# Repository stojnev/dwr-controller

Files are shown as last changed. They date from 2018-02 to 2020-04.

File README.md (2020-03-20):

# dŵr controller

"dŵr controller" ("dŵr") is a relatively simple closed loop snippet to provide two basic functionalities to a turntable drive system - (1) RPM counter and (2) feedback for an external motor controller.

It also aims to do some psychoacoustic majic in between code loops.

## Features

- Calculates RPM from up to 12 (*) control points on a turntable platter via a single sensor;
- Handles an external controller through a rough PI loop (running speed, speed mode (33/45) and control method);
- Rough PI parameter auto-tune;
- Dynamically calculates a standardized wow value, averaged over the control cycle.;

(*) Technically, can be as many as needed, or as many as can physically fit on the turntable platter.

## Description

"dŵr" acts principally as a tachometer, utilizing a combination of magnets attached to the underside of a turntable drive platter, and a single fixed location hall effect sensor, connected to an Arduino (Nano for most of principal development). This information is continuously displayed on an OLED screen controlled via I2C.

Assembled data derives a difference quotient from desired speed which is then used to send commands to an external controller. (**)

(**) Development has revolved mostly around the SG4 sinewave generator, courtesy of Pyramid on DIYAudio.com.

Additional features include:

- Calculation of wow as a primary component of W&F;
- Recording of standard play time to gauge cartridge life;
- Dynamic parameter logging for latter analyses. 

## Dependencies

- [OneButton](https://github.com/mathertel/OneButton) 
- [U8G2](https://github.com/olikraus/u8g2)

## Hardware

- Arduino Nano (or similar)
- Hall Effect Sensor (or an optical sensor)
- Magnets (or strips of reflective tape for an optical sensor)
- OLED (using a SSD1306 based 0.91" via I2C)
- BC337 (or similar NPN transistor) (***)
- 1kOhm resistors

(***) Replaced CD4066B switch as it was unreliable in this application.

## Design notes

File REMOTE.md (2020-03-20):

# dŵr controller

"dŵr controller" ("dŵr") uses two pushbuttons to access / activate various features. In order to have a minimal number of buttons, yet retain full functionality, dŵr relies on a combination of (1) various button events (short press, long press) and (2) turntable running state (spinning, not spinning).

* [LSP] - Left button press;
* [LDP] - Left button hold press;
* [RSP] - Right button press;
* [RDP] - Right button hold press;

Left button refers to momentary switch typically connected to pin 4, right button refers to switch typically connected to pin 5.

## Platter Not Spinning

* [LSP] Start rotation.
* [RDP] Access play time for cartridge life.

## Timer Mode Active

* [LDP] Reset play time for cartridge life.
* [RDP] Exit timer mode.

## Platter Spinning

* [LSP] Stop rotation.
* [LDP] Show calculated W&F.
* [RSP] Change rotation speed (33/45).
* [RDP] Switch between automatic speed regulation and manual speed regulation (no feedback).

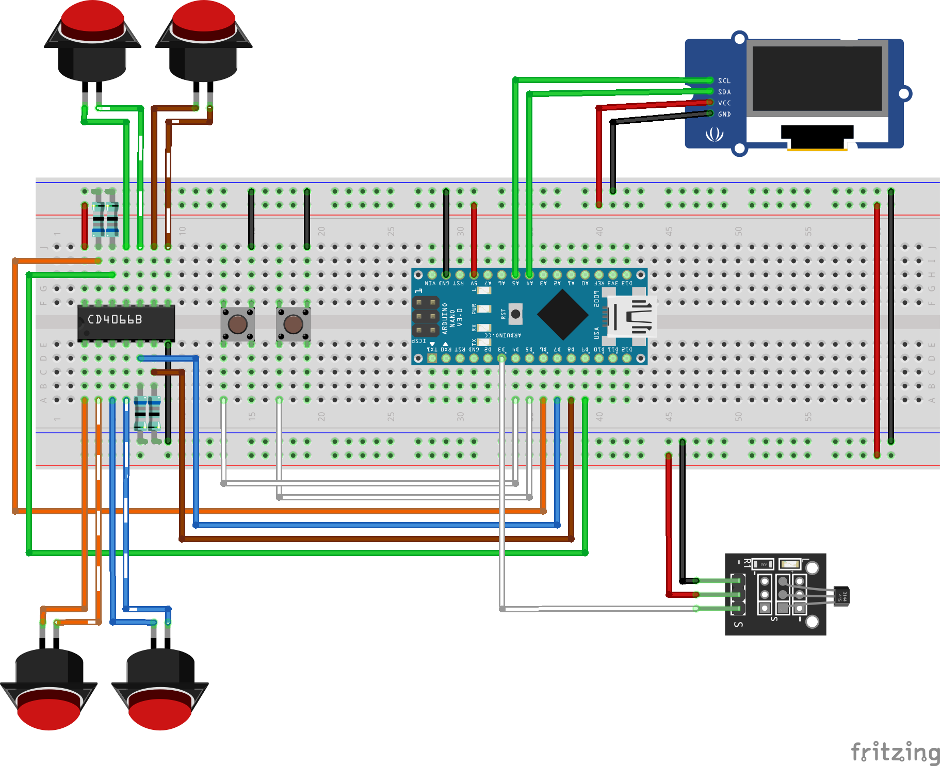
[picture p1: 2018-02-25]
breadboards/dwr-controller-v0.1.png

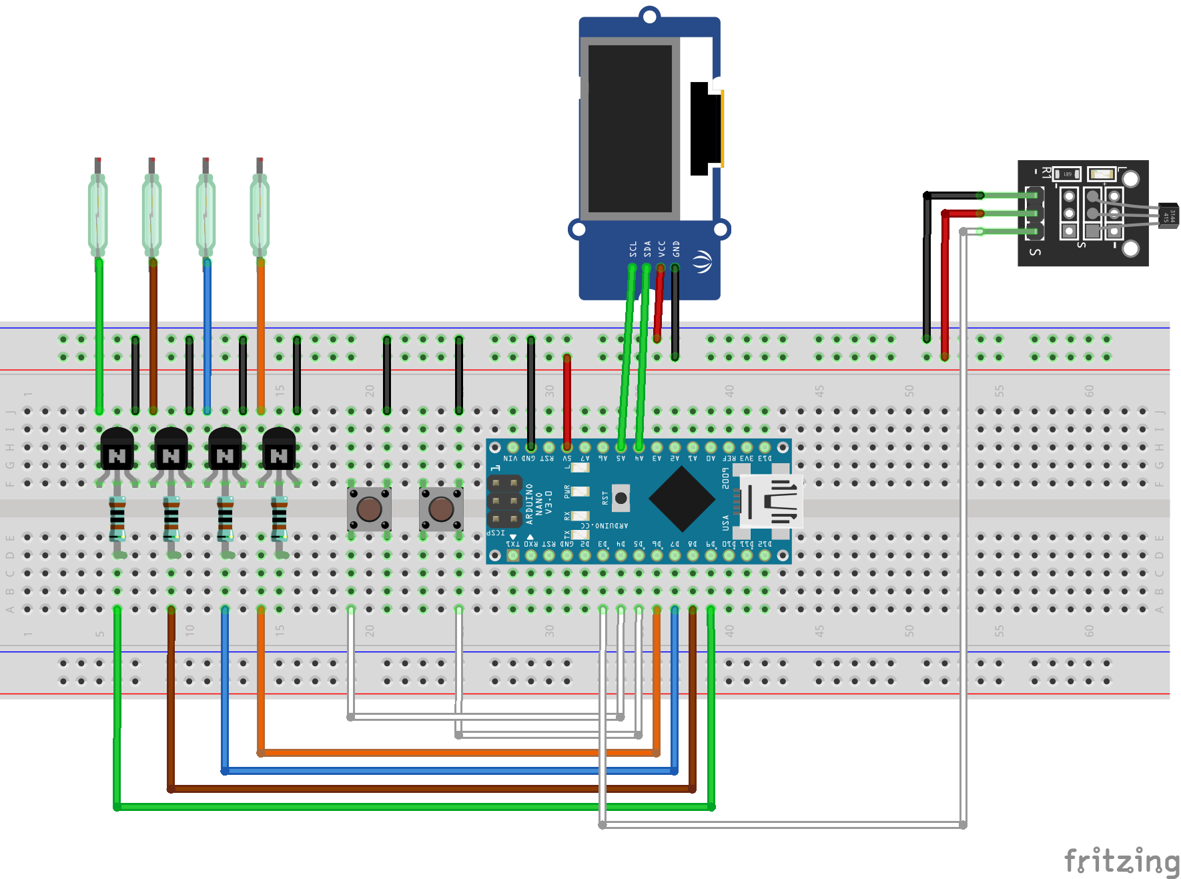
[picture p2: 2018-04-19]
breadboards/dwr-controller-v0.2.png

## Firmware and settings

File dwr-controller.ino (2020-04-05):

#include <OneButton.h>
#include <U8g2lib.h>
#include <EEPROM.h>

#define dwrlogo_width 60
#define dwrlogo_height 30
static const unsigned char dwrlogo_bits[] PROGMEM = {
  0x00, 0xf0, 0x03, 0x00, 0x02, 0x00, 0x00, 0x00, 0x00, 0xf0, 0x03, 0x00,
  0x07, 0x00, 0x00, 0x00, 0x00, 0xf0, 0x03, 0x80, 0x0f, 0x00, 0x00, 0x00,
  0x00, 0xf0, 0x03, 0xe0, 0x3f, 0x00, 0x00, 0x00, 0x00, 0xf0, 0x03, 0xf0,
  0x7f, 0x00, 0x00, 0x00, 0x00, 0xf0, 0x03, 0xf8, 0xfd, 0x00, 0x00, 0x00,
  0x00, 0xf0, 0x03, 0xf8, 0xf8, 0x00, 0x00, 0x00, 0x00, 0xf0, 0x03, 0x30,
  0x60, 0x00, 0x00, 0x00, 0x00, 0xf0, 0x03, 0x00, 0x00, 0x00, 0x00, 0x00,
  0x00, 0xf0, 0x03, 0x00, 0x00, 0x00, 0x00, 0x00, 0x00, 0xf0, 0x03, 0x00,
  0x00, 0x00, 0x00, 0x00, 0x00, 0xf0, 0x03, 0x00, 0x00, 0x00, 0x00, 0x00,
  0xc0, 0xf7, 0x03, 0x00, 0x02, 0x00, 0x80, 0x0f, 0xf0, 0xff, 0xe3, 0x07,
  0x07, 0x3f, 0xcf, 0x0f, 0xf8, 0xff, 0xe3, 0x87, 0x0f, 0x3f, 0xef, 0x0f,
  0xfc, 0xff, 0xc3, 0x87, 0x0f, 0x1f, 0xff, 0x0f, 0xfe, 0xff, 0xc3, 0xcf,
  0x9f, 0x1f, 0xff, 0x07, 0xfe, 0xff, 0xc3, 0xef, 0xbf, 0x1f, 0xff, 0x03,
  0x7f, 0xf0, 0x83, 0xef, 0xbf, 0x0f, 0x7f, 0x00, 0x3f, 0xe0, 0x83, 0xff,
  0xff, 0x0f, 0x3f, 0x00, 0x3f, 0xe0, 0x83, 0xff, 0xff, 0x0f, 0x3f, 0x00,
  0x3f, 0xe0, 0x03, 0xff, 0xff, 0x07, 0x3f, 0x00, 0x3f, 0xe0, 0x03, 0xff,
  0xfd, 0x07, 0x3f, 0x00, 0x7e, 0xf0, 0x03, 0xff, 0xf8, 0x07, 0x3f, 0x00,
  0xfe, 0xff, 0x03, 0x7e, 0xf0, 0x03, 0x3f, 0x00, 0xfc, 0xff, 0x03, 0x7e,
  0xf0, 0x03, 0x3f, 0x00, 0xfc, 0xff, 0x03, 0x3c, 0xe0, 0x01, 0x3f, 0x00,
  0xf8, 0xbf, 0x03, 0x1c, 0xc0, 0x01, 0x3f, 0x00, 0xe0, 0x8f, 0x03, 0x1c,
  0xc0, 0x01, 0x3f, 0x00, 0x80, 0x07, 0x00, 0x08, 0x80, 0x00, 0x3f, 0x00
};

U8G2_SSD1306_128X32_UNIVISION_F_HW_I2C u8g2(U8G2_R0, U8X8_PIN_NONE);

#define pinSensor 3
#define pinButtonSTB 4
#define pinButtonSWT 5
#define pinSwitchSTB 6
#define pinSwitchSWT 7
#define pinSwitchUP 8
#define pinSwitchDWN 9

int pseudoClickDelay = 25;
const int triggerNumber = 4; // Indicates the number of sensor triggers per rotation.
boolean debugSerial = true; // Determines if output written to serial (mostly if not exclusively for debugging purposes).
boolean tachometerOnly = false; // A setting of "true" disables pseudoClickButton() and switchRotationSpeed() for the code to work as tachometer only.
volatile unsigned long timeHallNew[8]; volatile unsigned long timeHallPrevious[8]; // Variables pairs to hold new and old times for sensor triggers - arrays are provisioned to account for a maximum of 8 sensor triggers.
boolean activeSpin = false; boolean justStarted = true; boolean modeAutomatic = true; // Variables to indicate whether (1) actively spinning, (2) just started spinning (legacy purpose) and (3) status of automatic correction.
long countSpin = 0; int countTempSpin = 0; // Variables to hold (1) number of full spins since start and (2) intermediary spin portions between full spins based on number of sensor triggers.
int spinSpeed = 0; // Variable to hold speed of spinning, where 0 = 33.33 and 1 = 45.00.
int countMessageDisplaySpins = 1; int waitingCycle = 0; long stoppingTime = 2500000; // Indicates (1) the number of rotations a display message is active before being replaced with RPM, (2) represents intermediary counter and (3) determines the amount of microseconds elapsed after which the platter is considered stopped.
int correctionSpin = 3; int correctionSpinShort = 2; long correctionSpinCount = 0; int correctionMovement = 5; // Indicates (1) number of rotations to wait for applying correction with small corrections, (2) number of rotations to wait for applying correction with large corrections, (3) temporary spin count and (4) maximum amount of steps to correct per cycle.
float correctionQ = 0.01; // Indicates the difference quotient from standard speed to activate automatic correction.
float derivedQ = 0.01; // Indicates the correction in RPM derived from a single 0.01Hz step (single "click").
float totalWF = 0;
boolean averageCalc = true, averageCompleted = false; const int averageTotal = 16; int averageCount = 0; float averageValues[averageTotal]; boolean averageFlip = false; // Indicates (1) whether to do averaging and (2) if first pass of averaging completed, (3) number of passes for each averaging.
float fixRPM = 0, fixSteps = 0; // Variables for programmatic calculation of derivedQ.
const float setQ = 0.01;
unsigned long timerCurrentMicros = 0, timerPreviousMicros = 0;
const int timerSlots = 4; int timerX[timerSlots]; const int timerMessageWait = 5000; long timerMessage = 0; boolean timerShown = false;

OneButton buttonSTB(pinButtonSTB, true);
OneButton buttonSWT(pinButtonSWT, true);

void setup()
{
  // Correct spin counting variables when using more than one trigger per spin cycle.
  countMessageDisplaySpins = countMessageDisplaySpins * triggerNumber;

  // Initialize buttons, switches and displays.
  initializeButtonsSwitchesSensors();
  u8g2.begin();
  drawLogo();

  if (debugSerial) {
    Serial.begin(9600);
  }
}

void loop()
{
  buttonSTB.tick();
  buttonSWT.tick();
  if (timerMessage > 0)
  {
    if (millis() > (timerMessage + timerMessageWait))
    {
      timerMessage = 0;
      timerShown = false;
      drawLogo();
    }
  }
  if (activeSpin)
  {
    unsigned long currentMicros = micros();
    checkTimer();
    if (justStarted)
    {
      writeToDisplay(3);
      justStarted = false;
    }
    if (timeHallNew[countTempSpin] > timeHallPrevious[countTempSpin]) {
      if (countSpin > 1) { showRPM(); }
    }
    else if (currentMicros - timeHallNew[countTempSpin] > stoppingTime) // Show waiting message after ~2.5 seconds of no new pulses, but only if pulses were detected.
    {
      stopSpin();
    }
    timeHallPrevious[countTempSpin] = timeHallNew[countTempSpin];
    delay(pseudoClickDelay);
  }
}

void stopSpin()
{
  // Default to 33.33 RPM to allow for smoother start-up.
  spinSpeed = 0;
  digitalWrite(pinSwitchSWT, LOW);

  // Reset active rotation variables.
  activeSpin = false;
  countSpin = 0;
  countTempSpin = 0;
  correctionSpinCount = 0;
  drawLogo();
  averageCount = 0;
  averageCompleted = false;
  fixSteps = 0;
  timerCurrentMicros = 0;
  timerPreviousMicros = 0;
  timerMessage = 0;

}

void initializeButtonsSwitchesSensors()
{
  if (!tachometerOnly)
  {
    for (int p = 6; p <= 9; p++)
    {
      pinMode(p, OUTPUT);
      digitalWrite(p, LOW);
    }
    buttonSTB.attachClick(startOperation);
    buttonSTB.attachLongPressStart(clearTimer);
    buttonSWT.attachClick(switchRotationSpeed);
    buttonSWT.attachLongPressStart(switchAutomaticMode);
  }
  pinMode(pinSensor, INPUT_PULLUP);
  attachInterrupt(digitalPinToInterrupt(pinSensor), triggerSensor, FALLING);
}

void startOperation()
{
  if (activeSpin)
  {
    stopSpin();
    activeSpin = false;
  }
  else
  {
    justStarted = true;
  }
  pseudoClickButton(pinSwitchSTB);
  timerMessage = 0;
}

void switchRotationSpeed()
{
  if (tachometerOnly) { return; }
  if (!activeSpin) { return; }
  spinSpeed++;
  if (spinSpeed > 1) {
    spinSpeed = 0;
    digitalWrite(pinSwitchSWT, LOW);
  }
  else {
    digitalWrite(pinSwitchSWT, HIGH);
  }
  correctionSpinCount = 0;
  averageCount = 0;
  averageCompleted = false;
  averageFlip = true;
  fixSteps = 0;
  writeToDisplay(2);
}

void switchAutomaticMode()
{
  if (tachometerOnly) {
    return;
  }
  if (!activeSpin) {
    writeToDisplay(4);
    return;
  }
  modeAutomatic = !modeAutomatic;
  writeToDisplay(1);
  fixSteps = 0;
}

void triggerSensor()
{
  countTempSpin++;
  if (countTempSpin > triggerNumber)
  {
    countSpin++;
    correctionSpinCount++;
    activeSpin = true;
    countTempSpin = 1;
  }
  timeHallNew[countTempSpin] = micros();
}

void showRPM()
{
  if ((timeHallNew[countTempSpin] == 0) || (timeHallPrevious[countTempSpin] == 0)) {
    return;
  }
  // Measured clock modifier.
  float ardFIX = 1.0055;
  float currentRPM = (60000000.0 / (timeHallNew[countTempSpin] - timeHallPrevious[countTempSpin])) * ardFIX;
  float currentX = currentRPM;
  if (!tachometerOnly)
  {
    if (correctionSpinCount > correctionSpin) // Rest time has completed, and platter has spun more cycles than correctionSpin.
    {
      if (modeAutomatic)
      {
        if (fixSteps > 1)
        {
          derivedQ = abs(currentRPM - fixRPM) / fixSteps;
          if (derivedQ > setQ) {
            derivedQ = setQ;
          }
          fixSteps = 0;
          fixRPM = 0;
        }
        float DQ = calculateDifferenceQ(currentRPM);
        if (abs(DQ) > correctionQ)
        {
          int correctX = floor(abs(DQ) / derivedQ); int correctDirection = 0; // Indicates direction for correction, where 0 = UP and 1 = DOWN.
          if (DQ < 0) {
            correctDirection = 1;
          }
          int stepsX = (correctX > correctionMovement ? correctionMovement : correctX);
          correctionSpinCount = ((correctX > correctionMovement * 2) ? (correctionSpin - correctionSpinShort) : 0); // Waits for correctionMovement rotations before applying new correction, or correctionSpinShort
          timeHallPrevious[countTempSpin] = timeHallNew[countTempSpin];
          fixRPM = currentRPM;
          fixSteps = stepsX;
          for (int x = 0; x < stepsX; x++)
          {
            pseudoClickButton(8 + correctDirection);
            delay(pseudoClickDelay * 2);
          }
        }
      }
    }
  }
  if (averageCalc)
  {
    averageValues[averageCount] = currentRPM;
    averageCount++;
    if (averageCount >= averageTotal)
    {
      averageCount = 0;
      if (!averageFlip)
      {
        averageCompleted = true;
      }
      else
      {
        averageFlip = false;
      }
    }
    if (averageCompleted)
    {
      float averageSum = 0; totalWF = 0; float SB = 33.3333;
      if (spinSpeed == 1) { SB = 45.0000; }
      for (int a = 0; a < averageTotal; a++)
      {
        averageSum += averageValues[a];
        totalWF += abs((averageValues[a] / SB) - 1);
      }
      currentRPM = averageSum / averageTotal;
      totalWF = totalWF / averageTotal * 100;
    }
  }
  if (debugSerial)
  {
    Serial.print(currentX, 4); Serial.print(" "); Serial.print(currentRPM, 4); Serial.print(" "); Serial.print(derivedQ, 4); Serial.print(" "); Serial.print(averageCount); Serial.print(" "); Serial.print(totalWF, 5); Serial.println();
  }
  writeToDisplay(currentRPM);
}

float calculateDifferenceQ(float rpmQ)
{
  float speedBase = 33.3333;
  if (spinSpeed == 1) {
    speedBase = 45.0000;
  }
  return speedBase - rpmQ;
}

// "Clicks" a button connected to the analog switch utilizing a pretedermined delay for debouncing purposes.
void pseudoClickButton(int pinButton)
{
  if (tachometerOnly) {
    return;
  }
  digitalWrite(pinButton, HIGH);
  delay(pseudoClickDelay);
  digitalWrite(pinButton, LOW);
  delay(pseudoClickDelay);
}

// Draws the logo using U8G2 paging.
void drawLogo(void) {
  u8g2.firstPage();
  do
  {
    u8g2.drawXBMP( 32, 1, dwrlogo_width, dwrlogo_height, dwrlogo_bits);
  }
  while (u8g2.nextPage());
}

// Writes (1) RPM to the display, (2) correction mode message, (3) speed change message, (4) total runtime, (5) clearing message and (6) W&F. TTW > 10 gets written as RPM. For values below that threshold, 1 = "Manual/Automatic Correction Mode Change", 2 = "33/45 Speed Change", 3 = "Starting Up" and 4 = "Runtime".
void writeToDisplay(float TTW)
{
  if (waitingCycle > 0) {
    waitingCycle--;  // Exit procedure if number of spins to show message has not expired.
    return;
  }
  u8g2.firstPage();
  do
  {
    if (TTW > 10)
    {
      u8g2.setFont(u8g2_font_logisoso32_tr);
      u8g2.setCursor(0, 32);
      u8g2.print(TTW, 2);
      if (modeAutomatic)
      {
        u8g2.setFont(u8g2_font_unifont_t_symbols);
        u8g2.drawGlyph(108, 16, 0x23f6);
        u8g2.drawGlyph(108, 28, 0x23f7);
      }
    }
    else
    {
      u8g2.setFont(u8g2_font_logisoso16_tr);
      u8g2.setCursor(0, 16);
      if (TTW == 1)
      {
        u8g2.print(modeAutomatic ? "AUTOMATIC" : "MANUAL");
        u8g2.setCursor(0, 32);
        u8g2.print("correction");
      }
      else if (TTW == 2)
      {
        u8g2.print(spinSpeed == 0 ? "33.33 rpm" : "45.00 rpm");
        u8g2.setCursor(0, 32);
        u8g2.print("movement");
      }
      else if (TTW == 3)
      {
        u8g2.print("STARTUP");
        u8g2.setCursor(0, 32);
        u8g2.print("calculations");
      }
      else if (TTW == 4)
      {
        int timerX1, timerX2;
        calculateRuntime(timerX1, timerX2);
        if (timerX1 > 0) {
          u8g2.print(timerX1);
          u8g2.print("hr ");
        }
        if (timerX2 >= 0) {
          u8g2.print(timerX2);
          u8g2.print("min");
        }
        u8g2.setCursor(0, 32);
        u8g2.print("runtime");
        timerMessage = millis();
        timerShown = true;
      }
      else if (TTW == 5)
      {
        u8g2.print("CLEARING");
        u8g2.setCursor(0, 32);
        u8g2.print("runtimes");
        timerMessage = millis();
      }
      else if (TTW == 6)
      {
        u8g2.print("W&F");
        u8g2.setCursor(40, 32);
        u8g2.print(totalWF, 3);
        u8g2.setCursor(90, 32);
        u8g2.print("%");
      }
      if (activeSpin) {
        waitingCycle = countMessageDisplaySpins;
        if (TTW == 6) { waitingCycle = countMessageDisplaySpins * 2; }
      }
    }
  }
  while ( u8g2.nextPage() );
}


void clearTimer()
{
  if (activeSpin)
  {
    writeToDisplay(6);
    return;
  }
  if (!timerShown)
  {
    return;
  }
  writeToDisplay(5);
  for (int e = 0; e <= timerSlots; e++) {
    EEPROM.write(e, 0);
  }
}

void checkTimer()
{
  if (timerCurrentMicros == 0 && timerPreviousMicros == 0)
  {
    timerCurrentMicros = micros();
    timerPreviousMicros = timerCurrentMicros;
  }
  else {
    timerCurrentMicros = micros();
  }
  int timerSeconds = (int) ((timerCurrentMicros - timerPreviousMicros) / 1000000);
  if (timerSeconds > 60)
  {
    for (int e = 0; e < timerSlots; e++)
    {
      byte valueX = EEPROM.read(e);
      timerX[e] = (int) valueX;
    }
    timerPreviousMicros = timerCurrentMicros;
    int changeX = timerSeconds;
    for (int e = 0; e < 4; e++)
    {
      timerX[e] += changeX;
      if (timerX[e] > 255)
      {
        changeX = timerX[e] - 255;
        timerX[e] = changeX;
        changeX = 1;
      }
      else
      {
        changeX = 0;
      }
      EEPROM.write(e, timerX[e]);
    }
  }
}

void calculateRuntime(int & calcX1, int & calcX2)
{
  long runtimeX = 0;
  for (int e = 0; e < timerSlots; e++)
  {
    int tempX = (int) EEPROM.read(e);
    if (tempX > 0) {
      runtimeX += tempX * pow(255, e);
    }
  }
  calcX2 = (runtimeX / 60) % 60;
  calcX1 = (int) (runtimeX / 3600);
}

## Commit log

2018-02-24 Reference to 4066.
    Added reference to CD4066B switch.
2018-02-25 Added breadboard.
    Added basic breadboard including 4066, external switches, hall effect breakout and sample OLED.
    [dwr-controller-v0.1.fzz]
2018-02-26 Corrected possible overflow.
    Due to micros() overflowing after ~71 minutes, RPM could stop updating as current variables were not always getting new values.
    [dwr-controller.ino]
2018-02-28 Added AVERAGE.
    The code will now calculate the average RPM and present those values instead of momentary feedback. Correction routines are not to be affected by average values.
    [dwr-controller.ino]
2018-03-22 Updated averaging routine.
    The averaging routine, when switched to 45rpm, halted the code after a few minutes due to averageCount not resetting under all conditions.
    [dwr-controller.ino]
2018-03-24 Added automatic Q calculation.
    The code relied on a fixed variable, derivedQ, to provide the size of the step a single "click" would effect on the external controller - this was easy but slightly inefficient due to inability to account for external variations. With this update, derivedQ is calculated automatically with every change effected to the external controller, provided it is large enough to produce an effective sample. Currently, the minimum is two changes (two steps).
    [dwr-controller.ino]
2018-04-07 Separated stopping routine.
    Slight refactor, moved stopping routine away from the main loop. Stopping via button now has immediate display reaction.
2018-04-10 Added PCB Gerber.
    Developed PCBs for controller (Arduino + CD4006B) and remote (buttons + OLED).
2018-04-18 Implemented total running timer.
    Implemented a feature to save the total running time of the motor. EEPROM stored, reset timer function included.
    [dwr-controller.ino]
2018-04-19 Updated PCB. Replaced CD4066B with a quad of BC337 transistors.
    PCB is now on version 0.2, due to using a quad of BC337 transistors in place of the CD4066B switch. Transistors have proven more reliable and less sensitive to current leakage.
    [dwr-controller-v0.2.fzz]
2018-05-08 Running timer triggers every minute.
    For consistency, and to avoid loss of data when power is lost, checkTimer() is back in the main loop, but triggered once a minute.
    [dwr-controller.ino]
2020-03-17 Update dwr-controller.ino
    Minor corrections.
    [dwr-controller.ino]
2020-04-05 Add clock modifier.
    Turns out (not surprisingly) that the clocking quality of crystals on Nano boards is... questionable. In order to compensate for this manufacturing drift, a new constant is added which needs to be measured on a board by board basis.
    [dwr-controller.ino]
2020-04-05 Added clock modifier.
    Turns out (not surprisingly) that the clocking quality of crystals on Nano boards is... questionable. In order to compensate for this manufacturing drift, a new constant is added which needs to be measured on a board by board basis. Measurement can be done via oscilloscope or via frequency drift with the help of a test record (300Hz tone / 1kHz tone).
    [dwr-controller.ino]
